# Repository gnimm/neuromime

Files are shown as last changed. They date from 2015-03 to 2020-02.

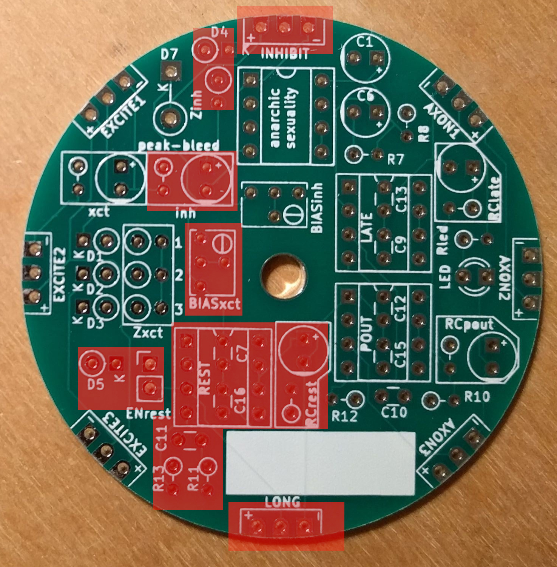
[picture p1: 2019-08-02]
1.0.1_minor_corrections_post_MUTEK/sketches_notes/dontsolder.jpg

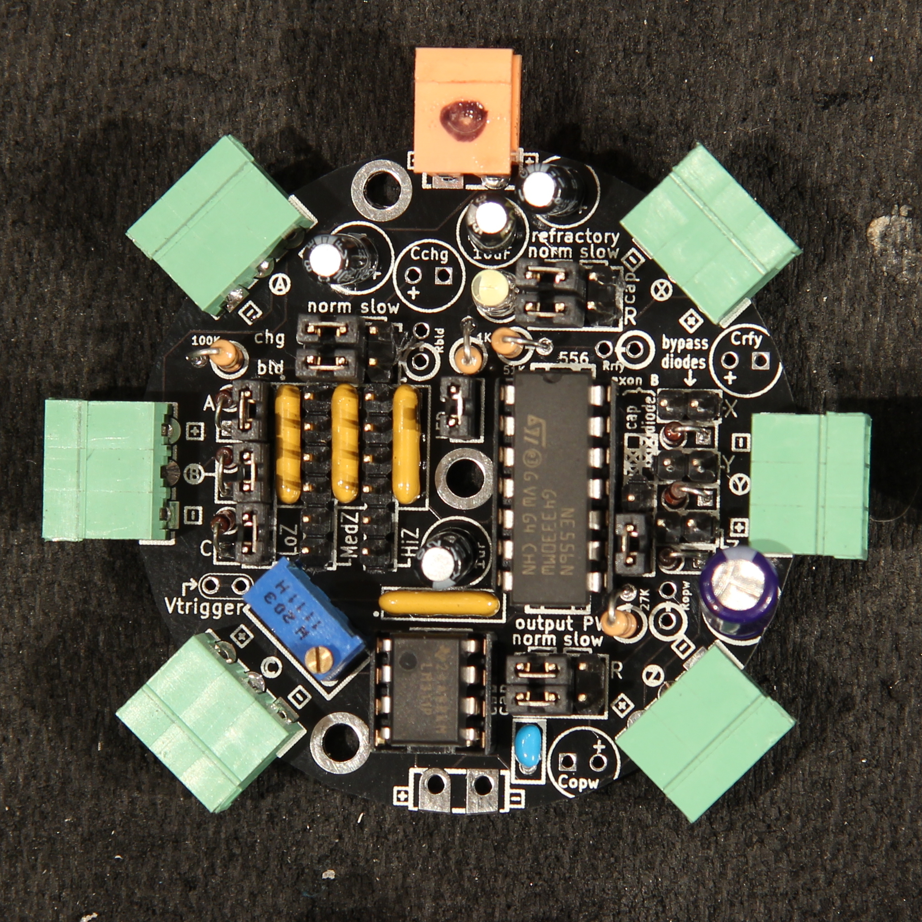
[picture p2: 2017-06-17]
ref/NEUROMIME_IO.jpg

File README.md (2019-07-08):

The “neuromime” is an electronic model of an organic nerve cell that can be interconnected in chains and loops. It is released here as an open-source hardware project in a collaborative effort by artists Norman White (original concept and design) and Peter Flemming (revision, expansion). Neuromimes are intended for (but not limited to) use in the creation of electro-physical artworks. Neuromimes can also function as the modular core of laboratory-style workshops where participants collectively generate an artwork for exhibition. Neuromimes are extensible building blocks, ideally suited to a collective making setting and/or generative, interactive artworks. Reminiscent of an exquisite corpse, they provide a framework that, while structured, is not scripted.

LINKS

Norman White speaking on the Neuromime at Interaccess (8'00"): https://www.youtube.com/watch?v=ue9ZF_hO-PE

Norman White on wikipedia: http://en.wikipedia.org/wiki/Norman_White

Norman White's website with other projects: http://normill.ca/

Peter Flemming's website with other projects: http://peterflemming.net

PROPERTIES OF AN ORGANIC NEURON

1. All-or-Nothing – It either fires completely or not at all (in this way it is "digital").

2. Temporal Summation – It can be made to fire by triggering one dendrite receptor repeatedly over time.

3. Spatial Summation – It can be made to fire by triggering several of its dendrite receptors simultaneously or virtually so.

4. Latency – It takes awhile for the impulse to travel from the dendrite receptor(s) along the axon to the output points (terminals).

5. Refractory Period – Once fired, it rests awhile before it can respond to stimuli again. 

TECHNICAL

-these folders contains files for a printed circuit board generated with KiCad, build: (2012-apr-16-27), http://www.kicad-pcb.org

-important technical annotation is contained in Norman's original schematic in the "ref" folder

-supplementary files (other schematics, visual information) are in the folder "ref"

-see the index below for detailed description of folder contents and files‎

INDEX (most folders have a detailed index as well)

1.0.0/

   ---this folder contains the Neuromime board files, schematics, fabrication outputs (Gerber etc.) done in KiCad

kicadlibs/

   ---folder contains footprint and schematic device libraries used in Neuromime not included in standard KiCad

ref/

   ---folder for supplementary files (Norman's original schematic, other visual information etc.)

LICENSE.txt

   ---Creative Commons license

README.md

   ---this file

TODO.txt

   ---errors, to do, future versions, suggestions, comments

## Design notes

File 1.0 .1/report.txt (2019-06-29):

Info: Backing up file "/home/gnimm/projects/schematics_pcb/neuromime/1.1.0/project_files/sym-lib-table" to file "/home/gnimm/projects/schematics_pcb/neuromime/1.1.0/project_files/rescue-backup/sym-lib-table-2018-11-04-21-16-39".
Info: Backing up file "/home/gnimm/projects/schematics_pcb/neuromime/1.1.0/project_files/neuromime_1.0.0.sch" to file "/home/gnimm/projects/schematics_pcb/neuromime/1.1.0/project_files/rescue-backup/neuromime_1.0.0-2018-11-04-21-16-39.sch".
Info: Backing up file "/home/gnimm/projects/schematics_pcb/neuromime/1.1.0/project_files/neuromime_1.0.0.pro" to file "/home/gnimm/projects/schematics_pcb/neuromime/1.1.0/project_files/rescue-backup/neuromime_1.0.0-2018-11-04-21-16-39.pro".
Info: Backing up file "/home/gnimm/projects/schematics_pcb/neuromime/1.1.0/project_files/neuromime_1.0.0-cache.lib" to file "/home/gnimm/projects/schematics_pcb/neuromime/1.1.0/project_files/rescue-backup/neuromime_1.0.0-cache-2018-11-04-21-16-39.lib".
Info: Backing up file "/home/gnimm/projects/schematics_pcb/neuromime/1.1.0/project_files/neuromime_1.0.0-rescue.lib" to file "/home/gnimm/projects/schematics_pcb/neuromime/1.1.0/project_files/rescue-backup/neuromime_1.0.0-rescue-2018-11-04-21-16-39.lib".
Info: Backing up file "/home/gnimm/projects/schematics_pcb/neuromime/1.1.0/project_files/neuromime_1.0.0-rescue.dcm" to file "/home/gnimm/projects/schematics_pcb/neuromime/1.1.0/project_files/rescue-backup/neuromime_1.0.0-rescue-2018-11-04-21-16-39.dcm".
Info: Adding library "neuromime_1.0.0-rescue", file "${KIPRJMOD}/neuromime_1.0.0-rescue.lib" to project symbol library table.
Symbol "3_RESISTOR_PACK_BUSSED" mapped to symbol library "neuromime_1.0.0-rescue".
Symbol "3_RESISTOR_PACK_BUSSED" mapped to symbol library "neuromime_1.0.0-rescue".
Symbol "3_RESISTOR_PACK_BUSSED" mapped to symbol library "neuromime_1.0.0-rescue".
Symbol "GND" mapped to symbol library "neuromime_1.0.0-rescue".
Symbol "CONN_1" mapped to symbol library "neuromime_1.0.0-rescue".
Symbol "CONN_1" mapped to symbol library "neuromime_1.0.0-rescue".
Symbol "GND" mapped to symbol library "neuromime_1.0.0-rescue".
Symbol "GND" mapped to symbol library "neuromime_1.0.0-rescue".
Symbol "CONN_1" mapped to symbol library "neuromime_1.0.0-rescue".
Symbol "TEST" mapped to symbol library "neuromime_1.0.0-rescue".
Symbol "CP" mapped to symbol library "neuromime_1.0.0-rescue".
Symbol "JUMPER3" mapped to symbol library "neuromime_1.0.0-rescue".
Symbol "VCC" mapped to symbol library "power".
Symbol "VCC" mapped to symbol library "power".
Symbol "VCC" mapped to symbol library "power".
Symbol "GND" mapped to symbol library "neuromime_1.0.0-rescue".
Symbol "CONN_3" mapped to symbol library "neuromime_1.0.0-rescue".
Symbol "CONN_3" mapped to symbol library "neuromime_1.0.0-rescue".
Symbol "CONN_3" mapped to symbol library "neuromime_1.0.0-rescue".
Symbol "3_RESISTOR_PACK_BUSSED" mapped to symbol library "neuromime_1.0.0-rescue".
Symbol "VCC" mapped to symbol library "power".
Symbol "GND" mapped to symbol library "neuromime_1.0.0-rescue".
Symbol "JUMPER" mapped to symbol library "neuromime_1.0.0-rescue".
Symbol "JUMPER" mapped to symbol library "neuromime_1.0.0-rescue".
Symbol "CONN_3" mapped to symbol library "neuromime_1.0.0-rescue".
Symbol "JUMPER" mapped to symbol library "neuromime_1.0.0-rescue".
Symbol "DIODE" mapped to symbol library "neuromime_1.0.0-rescue".
Symbol "DIODE" mapped to symbol library "neuromime_1.0.0-rescue".
Symbol "JUMPER" mapped to symbol library "neuromime_1.0.0-rescue".
Symbol "CONN_3" mapped to symbol library "neuromime_1.0.0-rescue".
Symbol "JUMPER" mapped to symbol library "neuromime_1.0.0-rescue".
Symbol "JUMPER" mapped to symbol library "neuromime_1.0.0-rescue".
Symbol "GND" mapped to symbol library "neuromime_1.0.0-rescue".
Symbol "VCC" mapped to symbol library "power".
Symbol "C" mapped to symbol library "neuromime_1.0.0-rescue".
Symbol "VCC" mapped to symbol library "power".
Symbol "GND" mapped to symbol library "neuromime_1.0.0-rescue".
Symbol "JUMPER" mapped to symbol library "neuromime_1.0.0-rescue".
Symbol "DIODE" mapped to symbol library "neuromime_1.0.0-rescue".
Symbol "DIODE" mapped to symbol library "neuromime_1.0.0-rescue".
Symbol "JUMPER" mapped to symbol library "neuromime_1.0.0-rescue".
Symbol "GND" mapped to symbol library "neuromime_1.0.0-rescue".
Symbol "JUMPER" mapped to symbol library "neuromime_1.0.0-rescue".
Symbol "DIODE" mapped to symbol library "neuromime_1.0.0-rescue".
Symbol "LED" mapped to symbol library "neuromime_1.0.0-rescue".
Symbol "JUMPER" mapped to symbol library "neuromime_1.0.0-rescue".
Symbol "R" mapped to symbol library "neuromime_1.0.0-rescue".
Symbol "GND" mapped to symbol library "neuromime_1.0.0-rescue".
Symbol "VCC" mapped to symbol library "power".
Symbol "C" mapped to symbol library "neuromime_1.0.0-rescue".
Symbol "GND" mapped to symbol library "neuromime_1.0.0-rescue".
Symbol "VCC" mapped to symbol library "power".
Symbol "GND" mapped to symbol library "neuromime_1.0.0-rescue".
Symbol "GND" mapped to symbol library "neuromime_1.0.0-rescue".
Symbol "C" mapped to symbol library "neuromime_1.0.0-rescue".
Symbol "GND" mapped to symbol library "neuromime_1.0.0-rescue".
Symbol "C" mapped to symbol library "neuromime_1.0.0-rescue".
Symbol "C" mapped to symbol library "neuromime_1.0.0-rescue".
Symbol "C" mapped to symbol library "neuromime_1.0.0-rescue".
Symbol "VCC" mapped to symbol library "power".
Symbol "CP" mapped to symbol library "neuromime_1.0.0-rescue".
Symbol "CP" mapped to symbol library "neuromime_1.0.0-rescue".
Symbol "CP" mapped to symbol library "neuromime_1.0.0-rescue".
Symbol "R" mapped to symbol library "neuromime_1.0.0-rescue".
Symbol "GND" mapped to symbol library "neuromime_1.0.0-rescue".
Symbol "JUMPER3" mapped to symbol library "neuromime_1.0.0-rescue".
Symbol "JUMPER3" mapped to symbol library "neuromime_1.0.0-rescue".
Symbol "R" mapped to symbol library "neuromime_1.0.0-rescue".
Symbol "VCC" mapped to symbol library "power".
Symbol "VCC" mapped to symbol library "power".
Symbol "GND" mapped to symbol library "neuromime_1.0.0-rescue".
Symbol "VCC" mapped to symbol library "power".
Symbol "GND" mapped to symbol library "neuromime_1.0.0-rescue".
Symbol "CP" mapped to symbol library "neuromime_1.0.0-rescue".
Symbol "CP" mapped to symbol library "neuromime_1.0.0-rescue".
Symbol "JUMPER3" mapped to symbol library "neuromime_1.0.0-rescue".
Symbol "VCC" mapped to symbol library "power".
Symbol "R" mapped to symbol library "neuromime_1.0.0-rescue".
Symbol "JUMPER3" mapped to symbol library "neuromime_1.0.0-rescue".
Symbol "GND" mapped to symbol library "neuromime_1.0.0-rescue".
Symbol "R" mapped to symbol library "neuromime_1.0.0-rescue".
Symbol "R" mapped to symbol library "neuromime_1.0.0-rescue".
Symbol "JUMPER3" mapped to symbol library "neuromime_1.0.0-rescue".
Symbol "JUMPER3" mapped to symbol library "neuromime_1.0.0-rescue".
Symbol "GND" mapped to symbol library "neuromime_1.0.0-rescue".
Symbol "R" mapped to symbol library "neuromime_1.0.0-rescue".
Symbol "CP" mapped to symbol library "neuromime_1.0.0-rescue".
Symbol "VCC" mapped to symbol library "power".
Symbol "GND" mapped to symbol library "neuromime_1.0.0-rescue".
Symbol "JUMPER" mapped to symbol library "neuromime_1.0.0-rescue".
Symbol "JUMPER" mapped to symbol library "neuromime_1.0.0-rescue".
Symbol "GND" mapped to symbol library "neuromime_1.0.0-rescue".
Symbol "CONN_2" mapped to symbol library "neuromime_1.0.0-rescue".
Symbol "CP" mapped to symbol library "neuromime_1.0.0-rescue".
Symbol "PWR_FLAG" mapped to symbol library "power".
Symbol "CONN_2" mapped to symbol library "neuromime_1.0.0-rescue".
Symbol "PWR_FLAG" mapped to symbol library "power".
Symbol "VCC" mapped to symbol library "power".
Symbol "CONN_3" mapped to symbol library "neuromime_1.0.0-rescue".
Symbol "POT" mapped to symbol library "neuromime_1.0.0-rescue".
Symbol "JUMPER" mapped to symbol library "neuromime_1.0.0-rescue".
Symbol "DIODE" mapped to symbol library "neuromime_1.0.0-rescue".
Symbol "556" mapped to symbol library "neuromime_1.0.0-rescue".
Symbol "LM311N" mapped to symbol library "neuromime_1.0.0-rescue".
Info: Symbol library table mapping complete!

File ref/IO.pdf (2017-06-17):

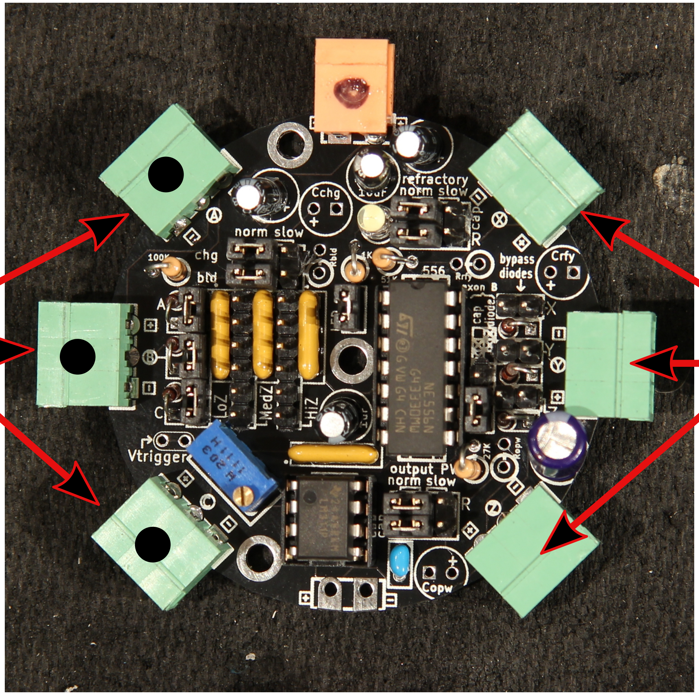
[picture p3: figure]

AXONS
(INPUTS)

DENDRITES
(OUTPUTS)

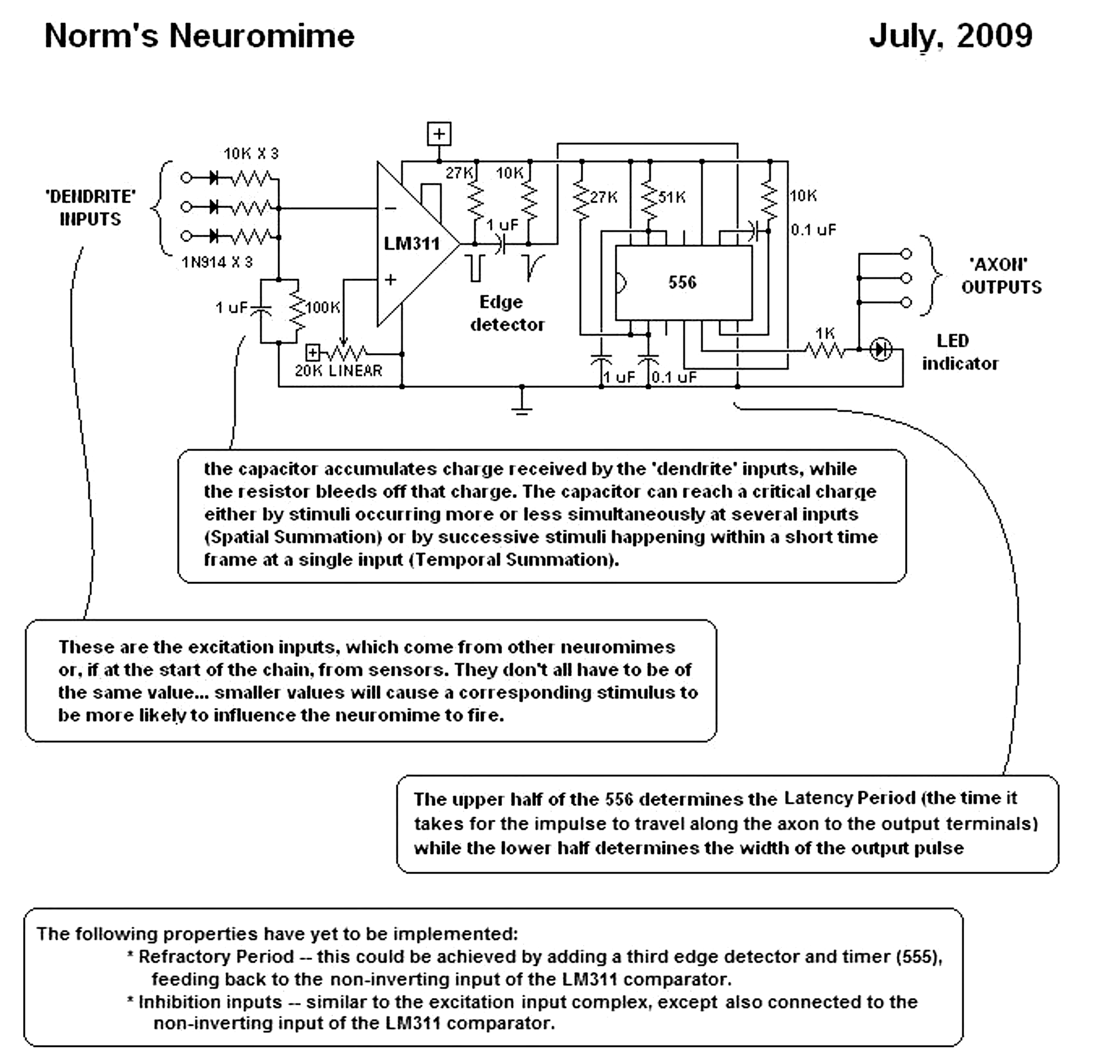
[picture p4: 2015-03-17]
ref/Neuromime_original_schematic_03.png

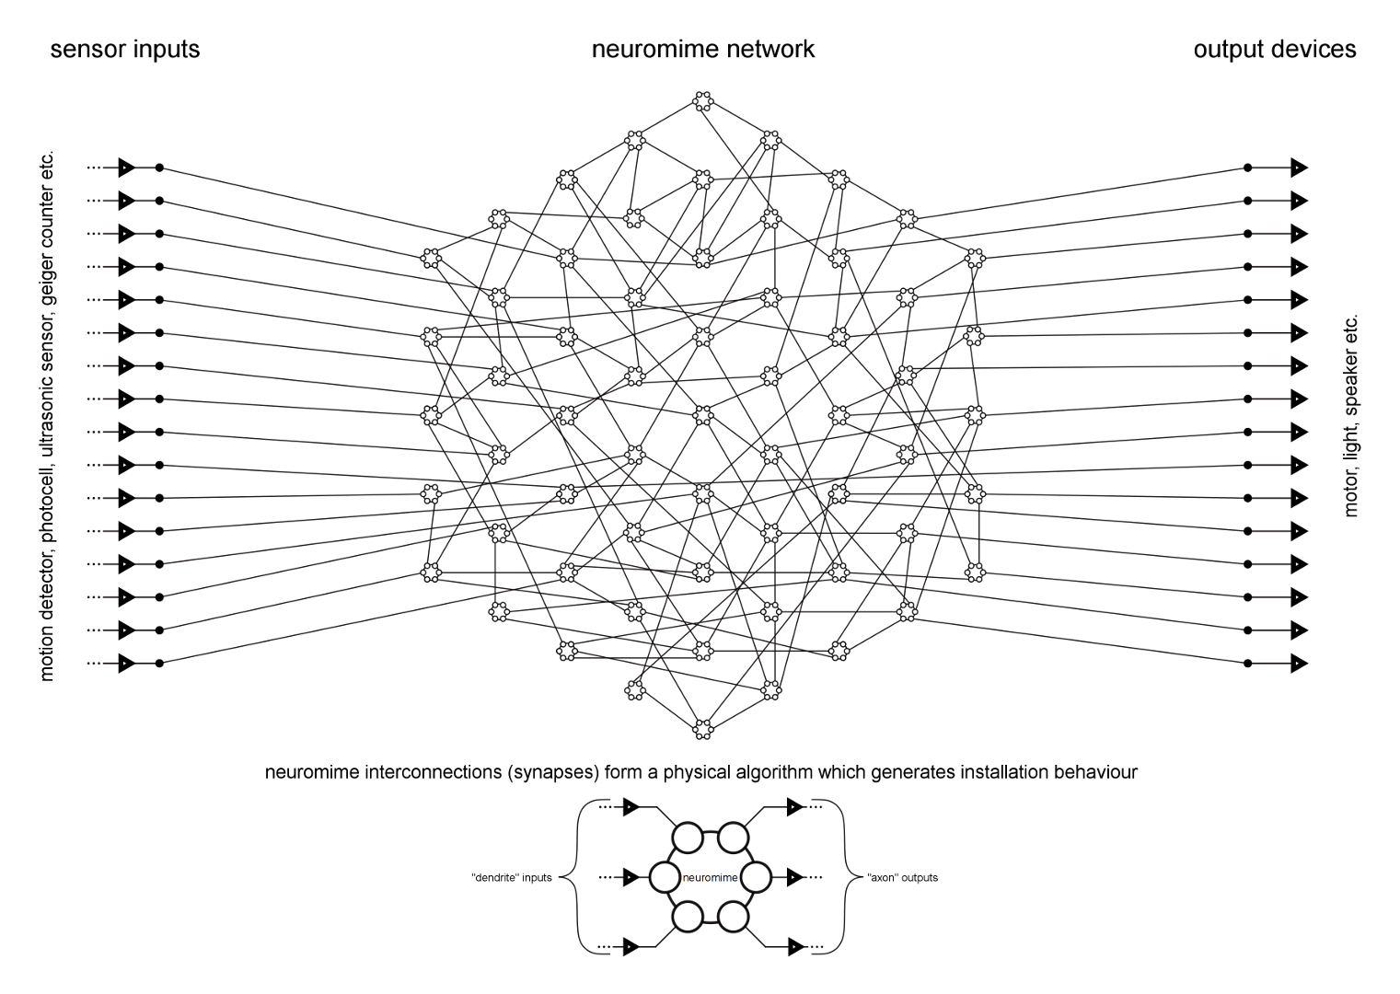
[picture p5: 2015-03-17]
ref/Neuromime_network_schematic.png

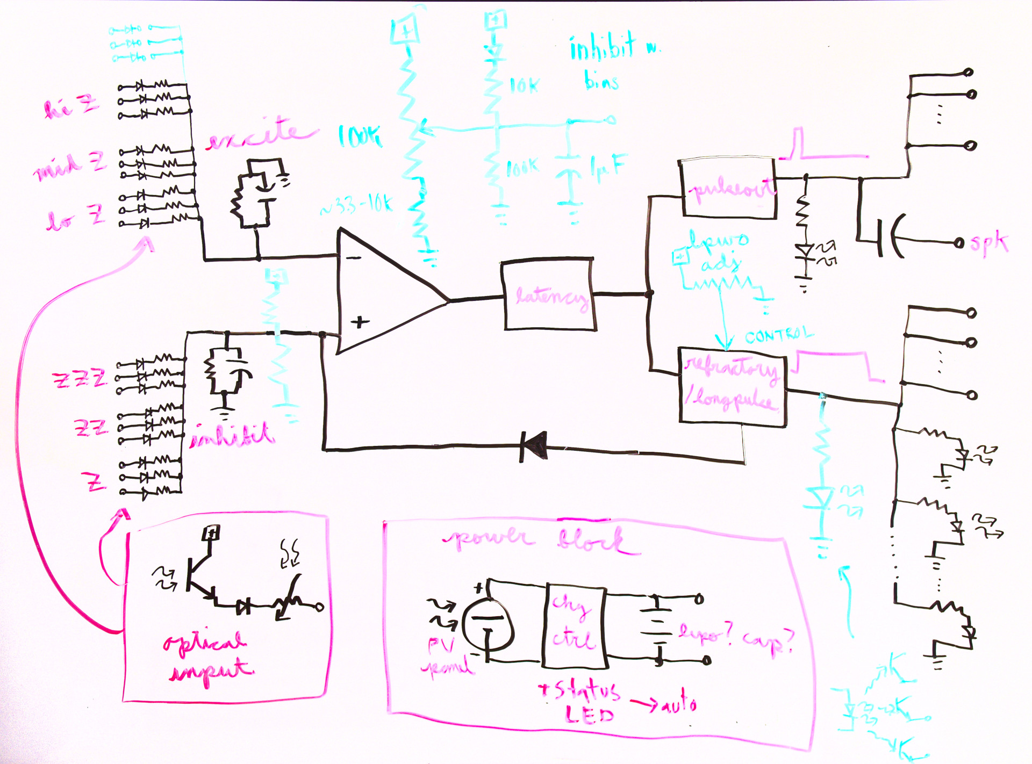
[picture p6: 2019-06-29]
1.0.1_minor_corrections_post_MUTEK/sketches_notes/2019-01_whiteboard_sketch_schematic_LORES.jpg

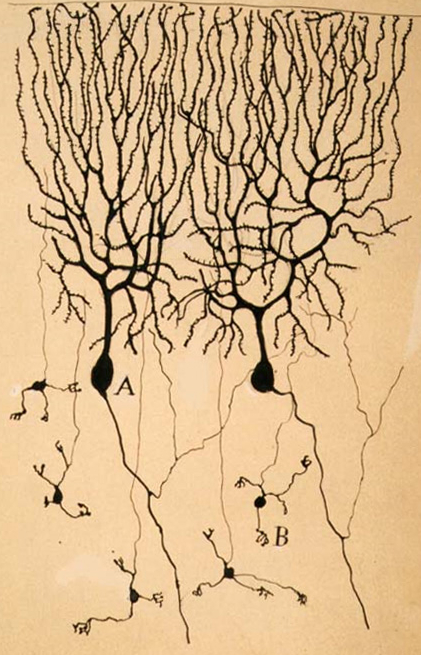
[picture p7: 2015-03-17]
ref/PurkinjeCell.jpg

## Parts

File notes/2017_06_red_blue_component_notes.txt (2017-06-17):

"red" neuromimes:
-quantity: 12
-implemented by Peter during EB residency, winter 2017 
-fiber optic output on axon B when 'cap' is selected w. axon B output jumper
-above jumper selects a 47 ohm resistor (soldered in place of 100uF cap)
-output PW cap, slow (red): 10uF
-output PW R, slow: 51K
timings:
		0.1uF	10uF
27K	2.97 mS	297 mS
51K	5.61 mS	561 mS

"blue" neuromimes:
-quantity: 9
-implemented by Peter for Stephen's 'Art and Artificial Life' class at NSCAD, summer 2017
-long output pulse
-output PW cap, slow: xxuF
-output PW R, slow: 47M
timings:
		0.1uF	100uF
27K	2.97 mS	xx S
47M	5.17 S	xx S

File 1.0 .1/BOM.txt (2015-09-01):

DIGIKEY PARTS LIST (shopping cart):
http://www.digikey.ca/short/tzpq7t

NB:
-this list is incomplete and in progress; missing at least the output LED (we used a 3mm super birght white LED), mating connector for the power pins and 8 pin DIP socket
-the power connectors used in orginal neuromime boards were purchased in Taiwan and identical ones do not seem to be available on Digikey (see alternate connectors below)
-possible cheaper alternates for connectors listed below; it should be possible to source nearly everything in bulk for cheap on sites like Ebay and/or Alibaba

ALTERNATE CONNECTORS:
3.96mm orange ones (for power):
   http://www.aliexpress.com/item/200PCS-HT396-HT396K-HT396R-2Pin-3-96mm-Right-Angle-Plug-in-Screw-Terminal-Block-ROHS/1079793360.html

3.5 mm green ones (for axon and dendrite connections):
   http://www.aliexpress.com/item/100PCS-2EDGK-3-81-3P-2EDGR-3-81-3P-2EDGK-2EDGR-3Pin-3-81mm-Right-Angle/1083116785.html

3.5mm combicon connectors from Digikey (would work for axon and dendrite connectors):
   277-1707-ND - terminal block - http://www.digikey.ca/product-detail/en/1984028/277-1707-ND/950835
   277-1750-ND - pin header - http://www.digikey.ca/product-detail/en/1945106/277-1750-ND/950878

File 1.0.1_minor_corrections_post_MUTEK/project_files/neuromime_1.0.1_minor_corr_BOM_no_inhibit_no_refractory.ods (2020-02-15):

Reference | Value | per, green boards A | per, green boards B | per yellow / white boards | extended | in inventory | need to order | preferred supplier | board label (if different from reference) | notes | MFPN | part link
C1 C17 | 10uF | 1 | 2 | 2 | 200 |  | 200 | dk | C17, green boards: RCrest (capacitor) C17, yellow/white boards: C_rest |  | 860010472002 | https://www.digikey.ca/product-detail/en/wurth-electronics-inc/860010472002/732-8625-1-ND/5728581
C4 C5 C6 C8 | 1uF | 1 | 4 | 4 | 400 |  | 400 | dk | C4: peak-bleed INH (capacitor) C5: peak-bleed XCT (capacitor) C8: Rclate (capacitor) |  | 860020672005 | https://www.digikey.ca/product-detail/en/wurth-electronics-inc/860020672005/732-8851-1-ND/5728796
C7 C9 C10 C11 C12 C13 C14 C15 C16 | 0.1uF | 3 | 8 | 8 | 800 |  | 800 | dk | C14: Rcpout (capacitor) | C7, C9, C12, C13, C15, C16 go on underside of board | C315C104M5U5TA | https://www.digikey.ca/product-detail/en/kemet/C315C104M5U5TA/399-4151-ND/817927
D1 D2 D3 D4 D5 | 1N4148 | 2 | 5 | 5 | 500 |  | 500 | dk |  | on green boards only: silkscreen is backwards, K indicates anode | 1N4148 | https://www.digikey.ca/product-detail/en/1N4148/1N4148FS-ND/458603/?itemSeq=298038621
D6 | LED 3mm | 0 | 1 | 1 | 100 |  | 100 | ali | LED |  | INL-3AB30 | https://www.digikey.ca/product-detail/en/inolux/INL-3AB30/1830-1005-ND/7604618
D7 | 1N4001 | 0 | 1 | 1 | 100 |  | 100 | dk |  |  | 1N4001-G | https://www.digikey.ca/product-detail/en/comchip-technology/1N4001-G/641-1310-1-ND/1979675
K1 K2 K3 K4 | 3p SIP socket | 1 | 4 | 4 | 400 |  | 400 | ali | K1: INHIBIT K2-4: EXCITE 1-3 |  | SSQ-103-02-T-S-RA | https://www.digikey.ca/product-detail/en/SSQ-103-02-T-S-RA/SAM1195-03-ND/1111409/?itemSeq=297654833
P2 P3 P4 P5 | 3p pin header | 1 | 4 | 4 | 400 |  | 400 | ali | P2-4: AXON 1-3 P5: LONG |  | PRPC003SGAN-M71RC | https://www.digikey.ca/product-detail/en/sullins-connector-solutions/PRPC003SGAN-M71RC/S1311EC-03-ND/2775451
R1 R2 R3 R4 R8 R10 R11 R12 R13 | 10K | 3 | 9 | 9 | 900 |  | 900 | dk | R1-3: Zxct R4: Zinh | R1-3 (Zxct) vertically mounted resistors, wire loop towards inside of board | CF14JT10K0 | https://www.digikey.ca/product-detail/en/CF14JT10K0/CF14JT10K0CT-ND/1830374/?itemSeq=297515842
R15 | 680R | 0 | 1 | 1 | 100 |  | 100 | dk | Rled |  | CF14JT680R | https://www.digikey.ca/product-detail/en/stackpole-electronics-inc/CF14JT680R/CF14JT680RCT-ND/1830346
R5 R6 | 100K | 1 | 2 | 2 | 200 |  | 200 | dk | R5: peak-bleed INH (resistor) R6: peak-bleed XCT (resistor) |  | CF14JT100K | https://www.digikey.ca/product-detail/en/stackpole-electronics-inc/CF14JT100K/CF14JT100KCT-ND/1830399
R7 R14 | 27K | 0 | 2 | 2 | 200 |  | 200 | dk | R14: Rcpout (resistor) |  | CF14JT27K0 | https://www.digikey.ca/product-detail/en/stackpole-electronics-inc/CF14JT27K0/CF14JT27K0CT-ND/1830385
R9 | 51K | 0 | 1 | 1 | 100 |  | 100 | dk | Rclate (resistor) |  | CF14JT51K0 | https://www.digikey.ca/product-detail/en/stackpole-electronics-inc/CF14JT51K0/CF14JT51K0CT-ND/1830392
R16 | 100K | 1 | 1 | 0 | 0 |  | 0 | dk | Rcrest (resistor)
RV1 RV2 | 10K trimmer | 1 | 2 | 3 | 300 |  | 300 | ali | RV1: BIASinh RV2: BIASxct |  | 1-1623849-0 | https://www.digikey.ca/product-detail/en/te-connectivity-passive-product/1-1623849-0/A105870-ND/2363126
RV3 | 1M trimmer | 0 | 0 | 1 | 100 |  | 100 | ali | RV3: VARrest
U1 | LM311 | 0 | 1 | 1 | 100 |  | 100 | ?? | anarchic sexuality |  | LM311P | https://www.digikey.ca/product-detail/en/texas-instruments/LM311P/296-1389-5-ND/277038
U2 U3 | 555 | 1 | 3 | 3 | 300 |  | 300 | ?? | U2: LATE U3: POUT U4: REST |  | SE555P | https://www.digikey.ca/product-detail/en/SE555P/296-9684-5-ND/380221/?itemSeq=297424092
SW1 | SW_push_dual | 0 | 0 | 1 | 100 | 0 | 100 | ali | sTaRt | optional start switch, white / yellow boards only, not required for all boards
IC sockets | 8 pin DIP | 1 | 4 | 4 | 400 |  | 400 | ali |  |  | ICS-308-T | https://www.digikey.ca/product-detail/en/adam-tech/ICS-308-T/2057-ICS-308-T-ND/9829299
spacer | 5/16” | 1 | 1 | 1 | 100 |  | 100 | ?? |  |  | 9912-312 | https://www.digikey.ca/product-detail/en/9912-312/492-1120-ND/586440/?itemSeq=297947991
# green boards A (no inhibit/refractory) |  |  | these are the boards used in August 2019 for MUTEK, with certain parts left unsoldered
# green boards B (blank) |  |  | these are the blank unused boards leftover from August 2019
# yellow / white boards (blank) | 100 |  | these are blank boards, printed after MUTEK in August 2019, with minor corrections arising

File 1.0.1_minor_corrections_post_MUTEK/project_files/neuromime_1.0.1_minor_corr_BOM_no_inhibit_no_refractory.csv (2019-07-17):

Reference | qty | Value | supplier/note | ext | MFPN | part link | qty. booards: | 100
C1 | 1 | 10uF |  | 100 | 860010472002 | https://www.digikey.ca/product-detail/en/wurth-electronics-inc/860010472002/732-8625-1-ND/5728581
C5 C6 C8 | 3 | 1uF |  | 300 | 860020672005 | https://www.digikey.ca/product-detail/en/wurth-electronics-inc/860020672005/732-8851-1-ND/5728796
C10 C11 C12 C13 C15 C16 C7 C9 C14 | 8 | 0.1uF |  | 800 | C315C104M5U5TA | https://www.digikey.ca/product-detail/en/kemet/C315C104M5U5TA/399-4151-ND/817927
D1 D2 D3 D4 D5 | 5 | 1N4148 |  | 500 | 1N4148 | https://www.digikey.ca/product-detail/en/1N4148/1N4148FS-ND/458603/?itemSeq=298038621
D6 | 1 | LED 3mm |  | 100 | INL-3AB30 | https://www.digikey.ca/product-detail/en/inolux/INL-3AB30/1830-1005-ND/7604618
D7 | 1 | 1N4001 |  | 100 | 1N4001-G | https://www.digikey.ca/product-detail/en/comchip-technology/1N4001-G/641-1310-1-ND/1979675
K1 K2 K3 K4 | 3 | 3p SIP socket |  | 400 | SSQ-103-02-T-S-RA | https://www.digikey.ca/product-detail/en/SSQ-103-02-T-S-RA/SAM1195-03-ND/1111409/?itemSeq=297654833K1 K2 K3 K4
P2 P3 P4 P5 | 3 | 3p pin header | Addison | 400
R1 R2 R3 R10 R11 R12 R13 R8 | 8 | 10K |  | 800 | CF14JT10K0 | https://www.digikey.ca/product-detail/en/CF14JT10K0/CF14JT10K0CT-ND/1830374/?itemSeq=297515842
R15 | 1 | 680R |  | 100 | CF14JT680R | https://www.digikey.ca/product-detail/en/stackpole-electronics-inc/CF14JT680R/CF14JT680RCT-ND/1830346
R6 | 1 | 100K |  | 100 | CF14JT100K | https://www.digikey.ca/product-detail/en/stackpole-electronics-inc/CF14JT100K/CF14JT100KCT-ND/1830399
R7 R14 | 2 | 27K |  | 200 | CF14JT27K0 | https://www.digikey.ca/product-detail/en/stackpole-electronics-inc/CF14JT27K0/CF14JT27K0CT-ND/1830385
R9 | 1 | 51K |  | 100 | CF14JT51K0 | https://www.digikey.ca/product-detail/en/stackpole-electronics-inc/CF14JT51K0/CF14JT51K0CT-ND/1830392
RV2 | 1 | 10K trimmer | Addison | 100 | 1-1623849-0 | https://www.digikey.ca/product-detail/en/te-connectivity-passive-product/1-1623849-0/A105870-ND/2363126
U1 | 1 | LM311 |  | 100 | LM311P | https://www.digikey.ca/product-detail/en/texas-instruments/LM311P/296-1389-5-ND/277038
U2 U3 | 2 | 555 |  | 200 | SE555P | https://www.digikey.ca/product-detail/en/SE555P/296-9684-5-ND/380221/?itemSeq=297424092
IC sockets | 3 | 8 pin DIP | Addison | 300 | ICS-308-T | https://www.digikey.ca/product-detail/en/adam-tech/ICS-308-T/2057-ICS-308-T-ND/9829299
spacer | 1 | 5/16” |  | 100 | 9912-312 | https://www.digikey.ca/product-detail/en/9912-312/492-1120-ND/586440/?itemSeq=297947991
pinheaders

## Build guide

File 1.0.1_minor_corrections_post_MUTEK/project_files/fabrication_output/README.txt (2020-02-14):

PCB NAME: neuromime_1.0.1_minor_corr
DATE: 2019-08-26
AUTHOR: Peter Flemming
CONTACT: info@peterflemming.net
PCB SOFTWARE USED: KiCad5/PcbNew

files in folder DRILL_DATA:
neuromime_1.0.1_minor_corr-NPTH_DRILLFILE.drl: Excellon drill file
neuromime_1.0.1_minor_corr-NPTH_DRILLMAP.pdf: drill map
neuromime_1.0.1_minor_corr_DRILL_REPORT.rpt: drill report
neuromime_1.0.1_minor_corr-NPTH_DRILLFILE.drl: Excellon drill file, non-plated through-holes
neuromime_1.0.1_minor_corr-NPTH_DRILLMAP.pdf: drill map, non-plated through-holes

files in folder GERBER_DATA:
neuromime_1.0.1_minor_corr_COPPER_BOTTOM_LAYER.gbr: copper layer, BOTTOM of board
neuromime_1.0.1_minor_corr_COPPER_TOP_LAYER.gbr: copper layer, TOP of board
neuromime_1.0.1_minor_corr_SOLDERMASK_BOTTOM.gbr: solder mask, BOTTOM of board
neuromime_1.0.1_minor_corr_SOLDERMASK_TOP.gbr: solder mask, TOP of board
neuromime_1.0.1_minor_corr_PCB_EDGES.gbr: PCB edges cut out
neuromime_1.0.1_minor_corr_SILKSCREEN_TOP.gbr: silkscreen/legend top of board
neuromime_1.0.1_minor_corr_SILKSCREEN_BOTTOM.gbr: silkscreen/legend bottom of board
neuromime_1.0.1_minor_corr_USER_REFERENCE.gbr: reference layer, contains dimensions, user notes, diagrams etc.

PRODUCTION NOTES:
-the GERBER format used by Pcbnew is RS274X format 4.6, mm, Leading zero omitted, Abs format

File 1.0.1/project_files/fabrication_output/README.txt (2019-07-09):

PCB NAME: neuromime_1.0.1
DATE: 2019-07-09
AUTHOR: Peter Flemming
CONTACT: info@peterflemming.net
PCB SOFTWARE USED: KiCad5/PcbNew

files in folder DRILL_DATA:
neuromime_1.0.1-NPTH_DRILLFILE.drl: Excellon drill file
neuromime_1.0.1-NPTH_DRILLMAP.pdf: drill map
*_DRILL_REPORT.rpt: drill report
neuromime_1.0.1-NPTH_DRILLFILE.drl: Excellon drill file, non-plated through-holes
neuromime_1.0.1-NPTH_DRILLMAP.pdf: drill map, non-plated through-holes

files in folder GERBER_DATA:
neuromime_1.0.1_COPPER_BOTTOM_LAYER.gbr: copper layer, BOTTOM of board
neuromime_1.0.1_COPPER_TOP_LAYER.gbr: copper layer, TOP of board
neuromime_1.0.1_SOLDERMASK_BOTTOM.gbr: solder mask, BOTTOM of board
neuromime_1.0.1_SOLDERMASK_TOP.gbr: solder mask, TOP of board
neuromime_1.0.1_PCB_EDGES.gbr: PCB edges cut out
neuromime_1.0.1_SILKSCREEN_TOP.gbr: silkscreen/legend top of board
neuromime_1.0.1_SILKSCREEN_BOTTOM.gbr: silkscreen/legend bottom of board
neuromime_1.0.1_USER_REFERENCE.gbr: reference layer, contains dimensions, user notes, diagrams etc.

PRODUCTION NOTES:
-the GERBER format used by Pcbnew is RS274X format 4.6, mm, Leading zero omitted, Abs format

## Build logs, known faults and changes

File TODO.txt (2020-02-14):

corrections/errors (Neuromime ver 1.0.0):
-correct refractory capacitor/resistor labelling to latency capacitor/resistor on top silkscreen layer
-correct axon labelling, top silkscreen layer

to do:
-implement inhibition input complex (on non-inverting input of LM311)
-implement refractory period (with another 555 timer)
-add bill-of-materials, in the meantime contact the maintainer (Peter)

suggestions/ideas:
-use individual 555 timers instead of 556 dual timer, this way could use low power version of 555, low power 556 not available
-surface mount version
-inhibition complex as out-board module for version 1.0.0
-make an output module (eg. SSR) in same form factor
-make a multiple cell board (eg. square or axonometric grid), with fixed number of external inputs and outputs, internal connections routable with jumpers, wirewrap connectors etc.

-high speed neuromimes, operating at, say, audio frequency (20hz-20khz)
-inspired by the "rate model", spiking neurons
-blinking lights become fading lights
-fiber optic connections then have variable strength (weights?) based on pulse frequency (LED brightness)
-could smooth high frequency (HF) neuromime outputs, connect directly to amp/speaker for wavering dissonant tones 
-HF outputs to dc motor speed (braitenberg?)

-add self-activation button on each neuron
-how to accomodate more than 3 I/O points?
-3D networks using bendable/rigid cabling or right-angle male-male headers, etc.
-neuromimes make Spiking Neural Networks (SNNs), which are more biologically plausible than continuous ANNs
-SNNs are used primarily in neuroscience reseach, while continuous ANNs are currently more "practical" problem solvers, i.e. they are easier to train for certain prediction problems and entirely the basis for the AI "revolution" circa 2016

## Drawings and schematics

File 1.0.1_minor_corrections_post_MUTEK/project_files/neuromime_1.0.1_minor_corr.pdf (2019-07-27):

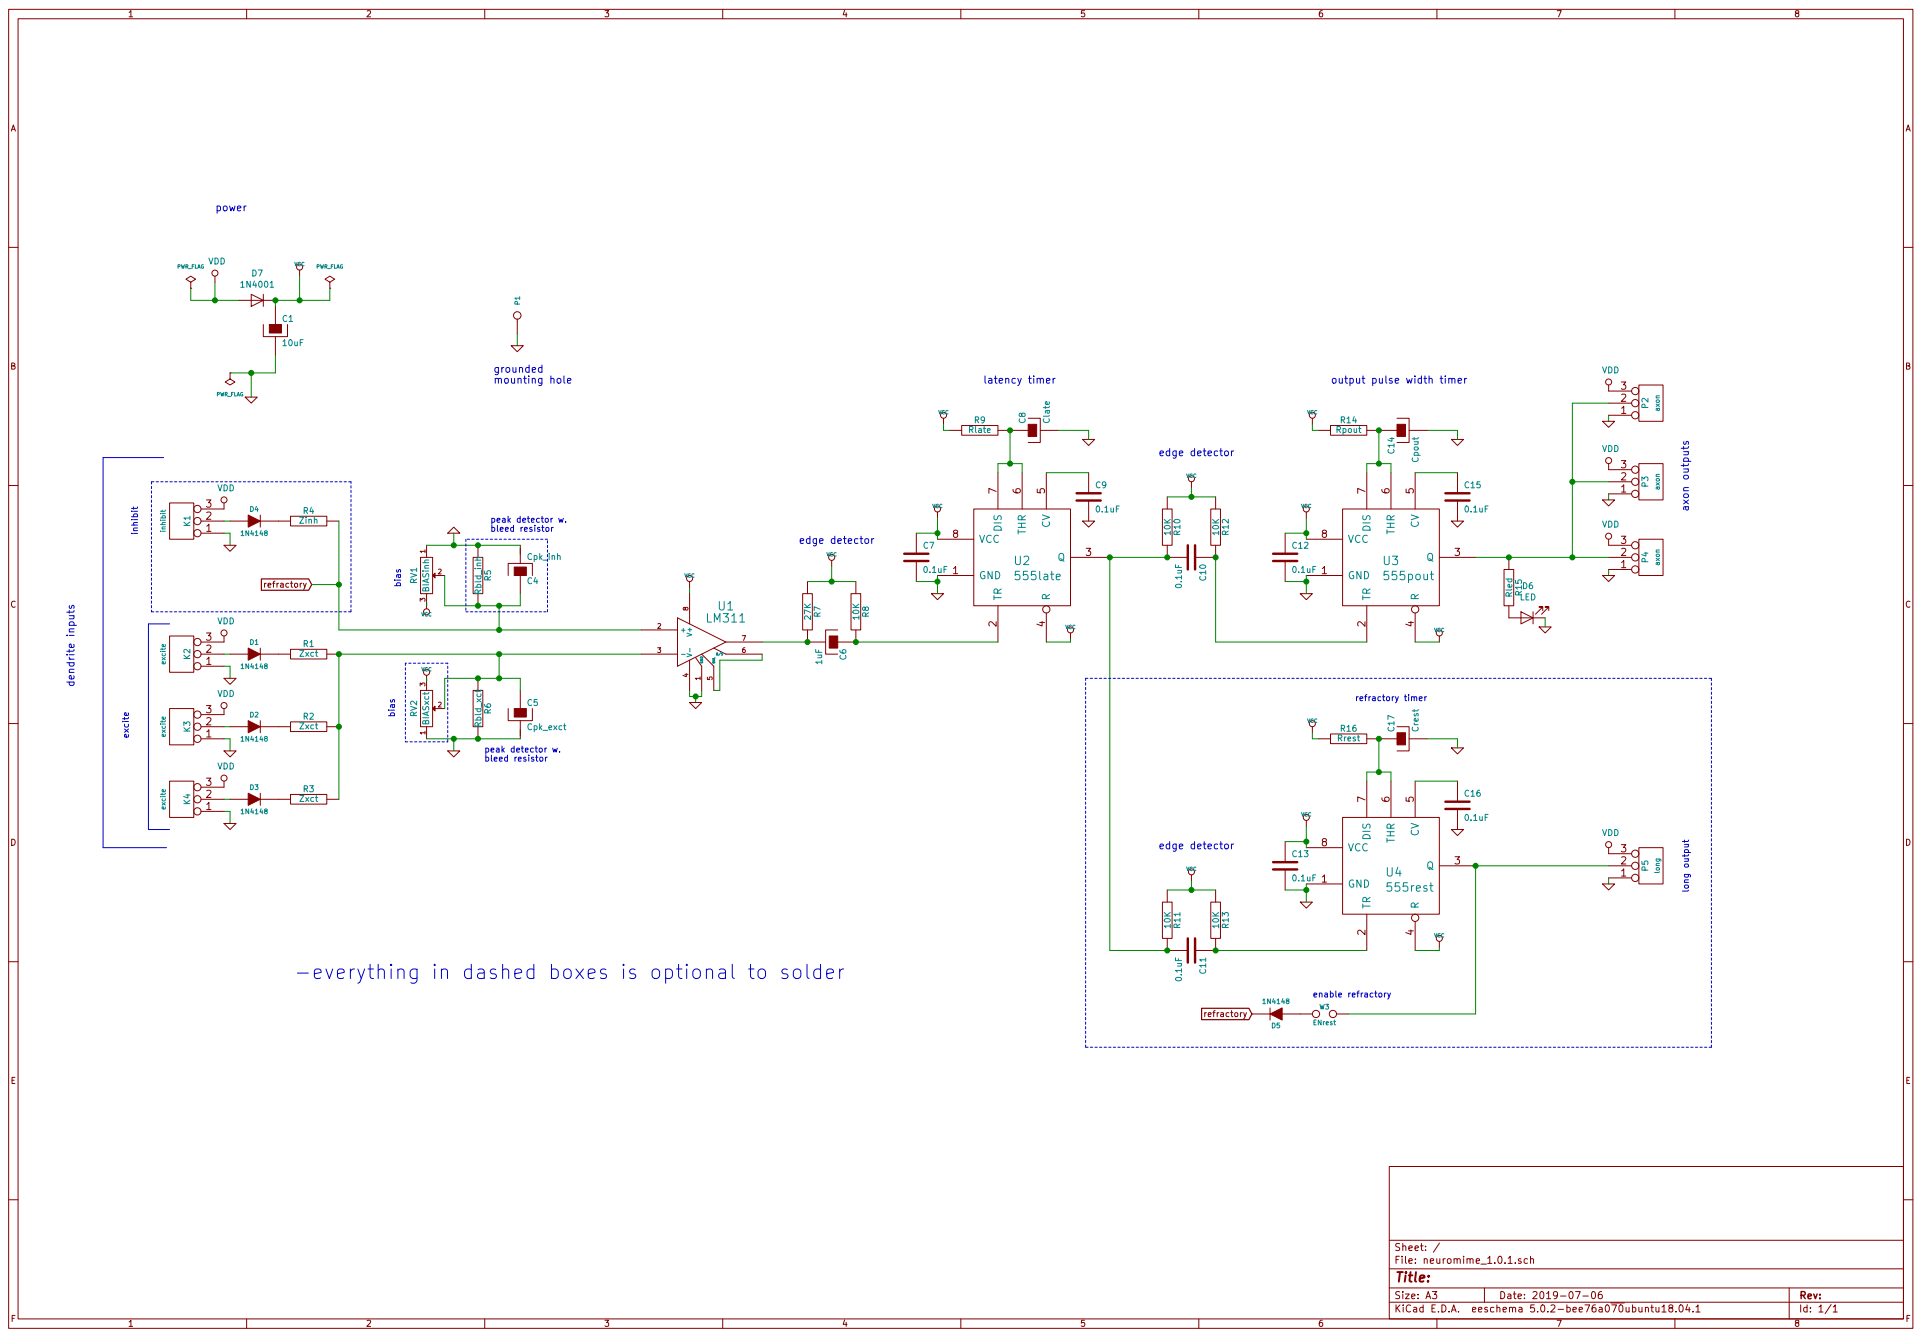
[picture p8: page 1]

Id: 1/1 Title: File: neuromime_1.0.1.sch Sheet: / P1 grounded mounting hole

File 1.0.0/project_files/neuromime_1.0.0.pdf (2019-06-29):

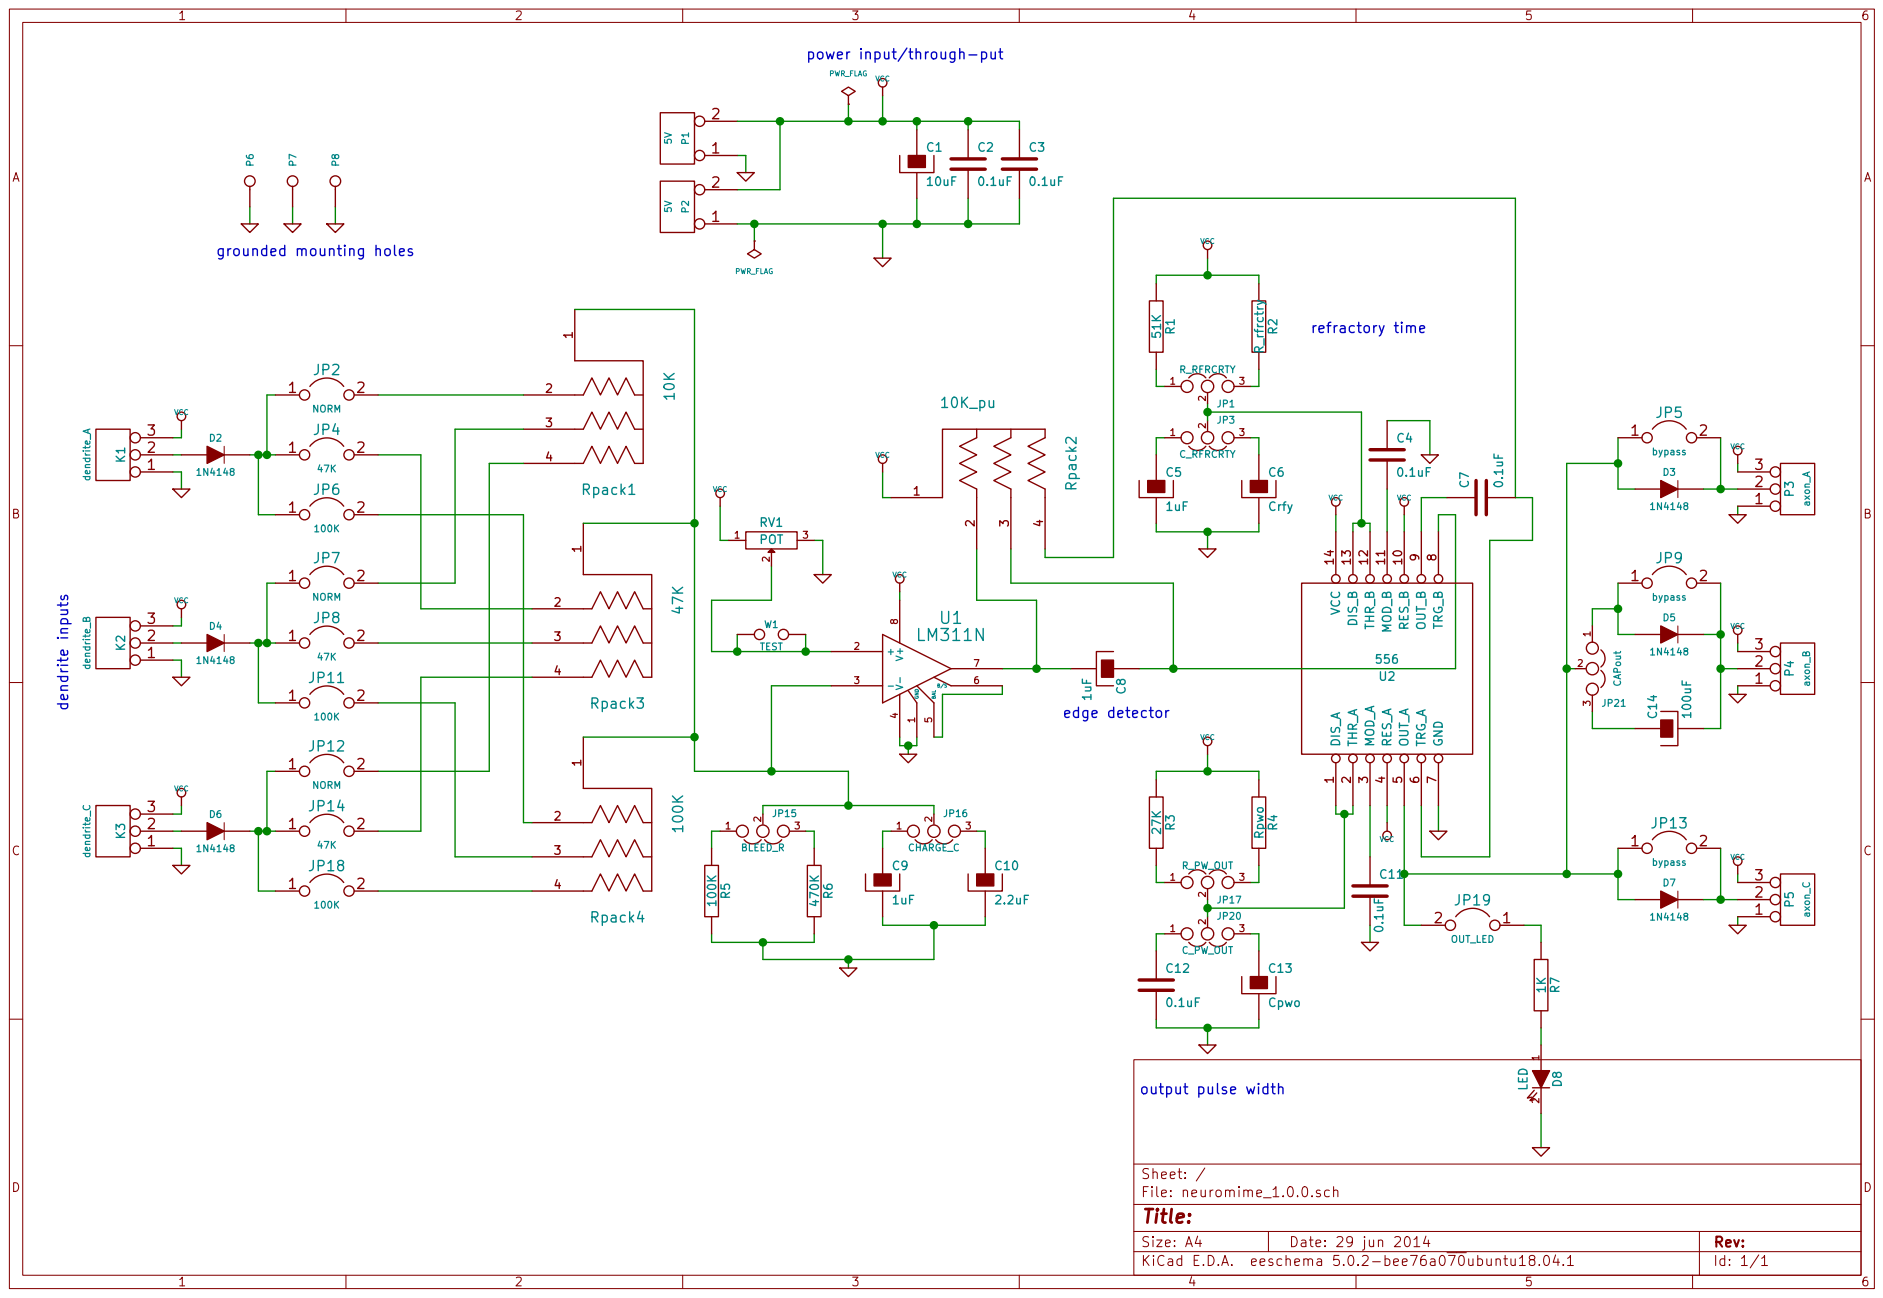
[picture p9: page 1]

0.1uF power input/through-put

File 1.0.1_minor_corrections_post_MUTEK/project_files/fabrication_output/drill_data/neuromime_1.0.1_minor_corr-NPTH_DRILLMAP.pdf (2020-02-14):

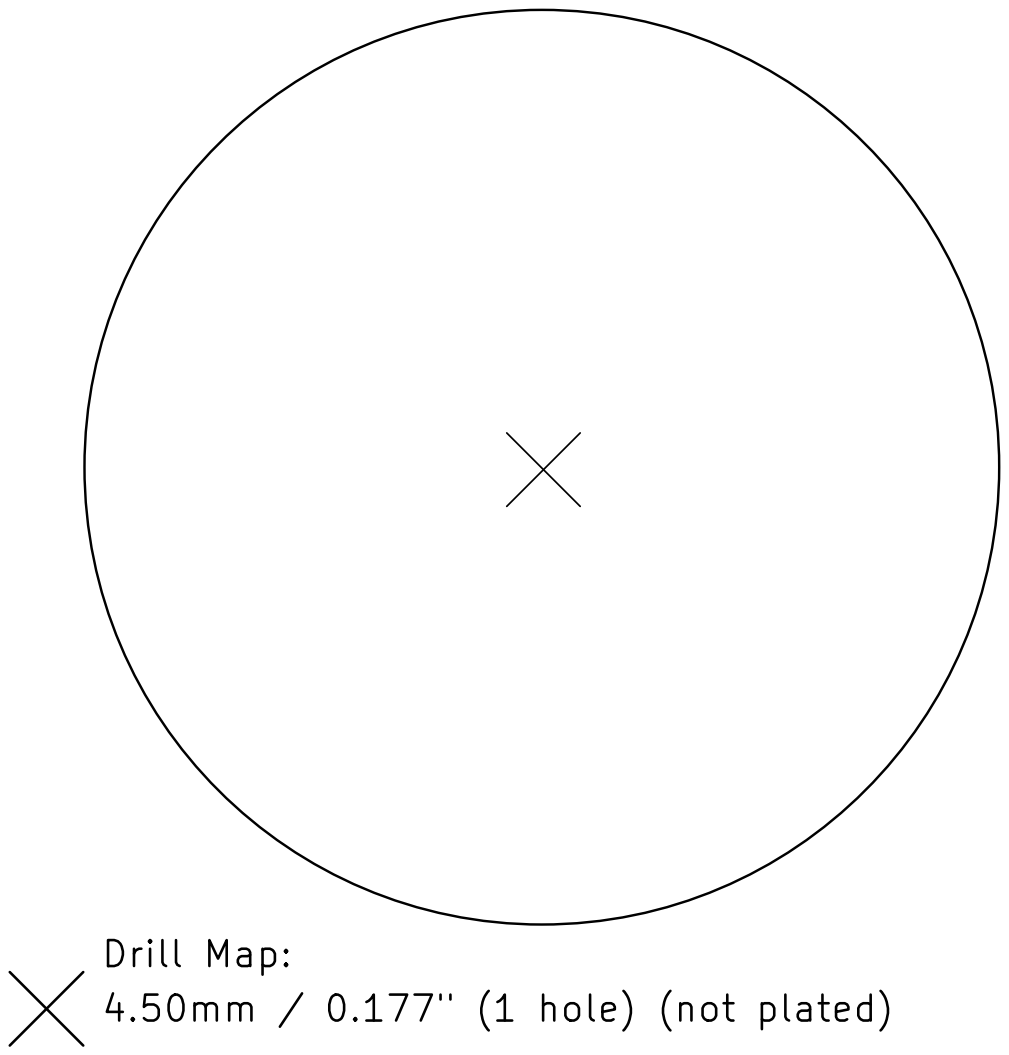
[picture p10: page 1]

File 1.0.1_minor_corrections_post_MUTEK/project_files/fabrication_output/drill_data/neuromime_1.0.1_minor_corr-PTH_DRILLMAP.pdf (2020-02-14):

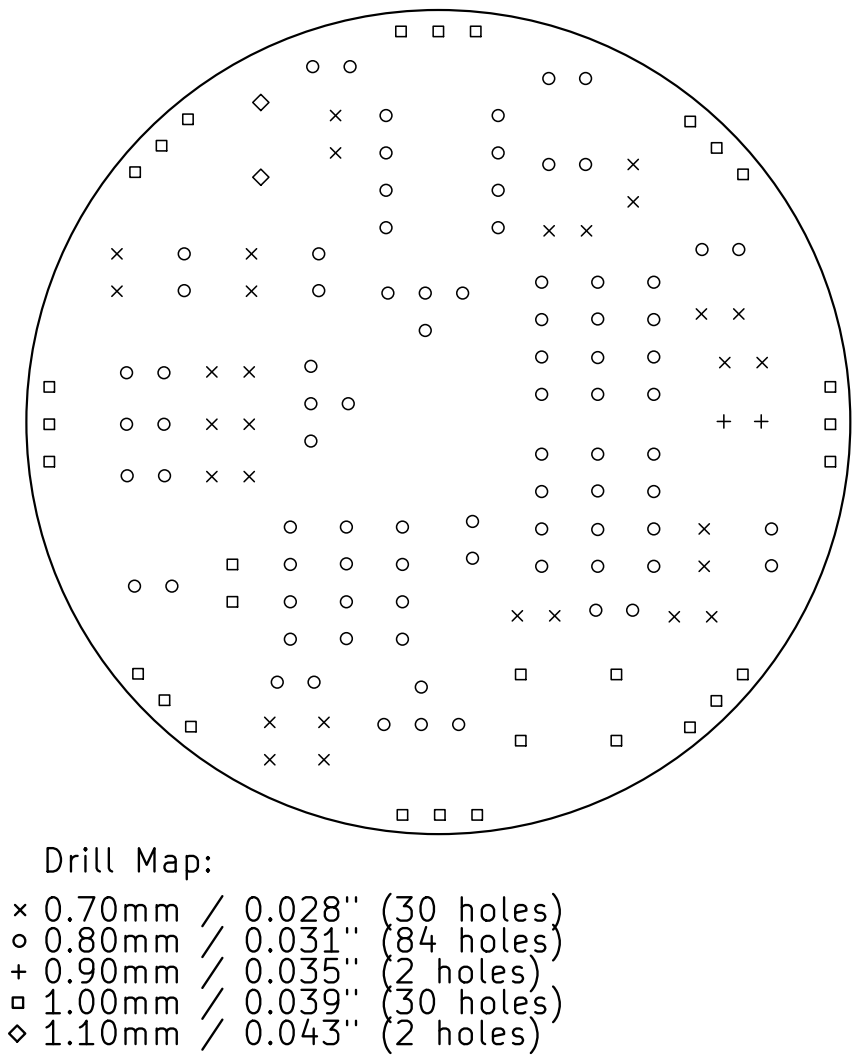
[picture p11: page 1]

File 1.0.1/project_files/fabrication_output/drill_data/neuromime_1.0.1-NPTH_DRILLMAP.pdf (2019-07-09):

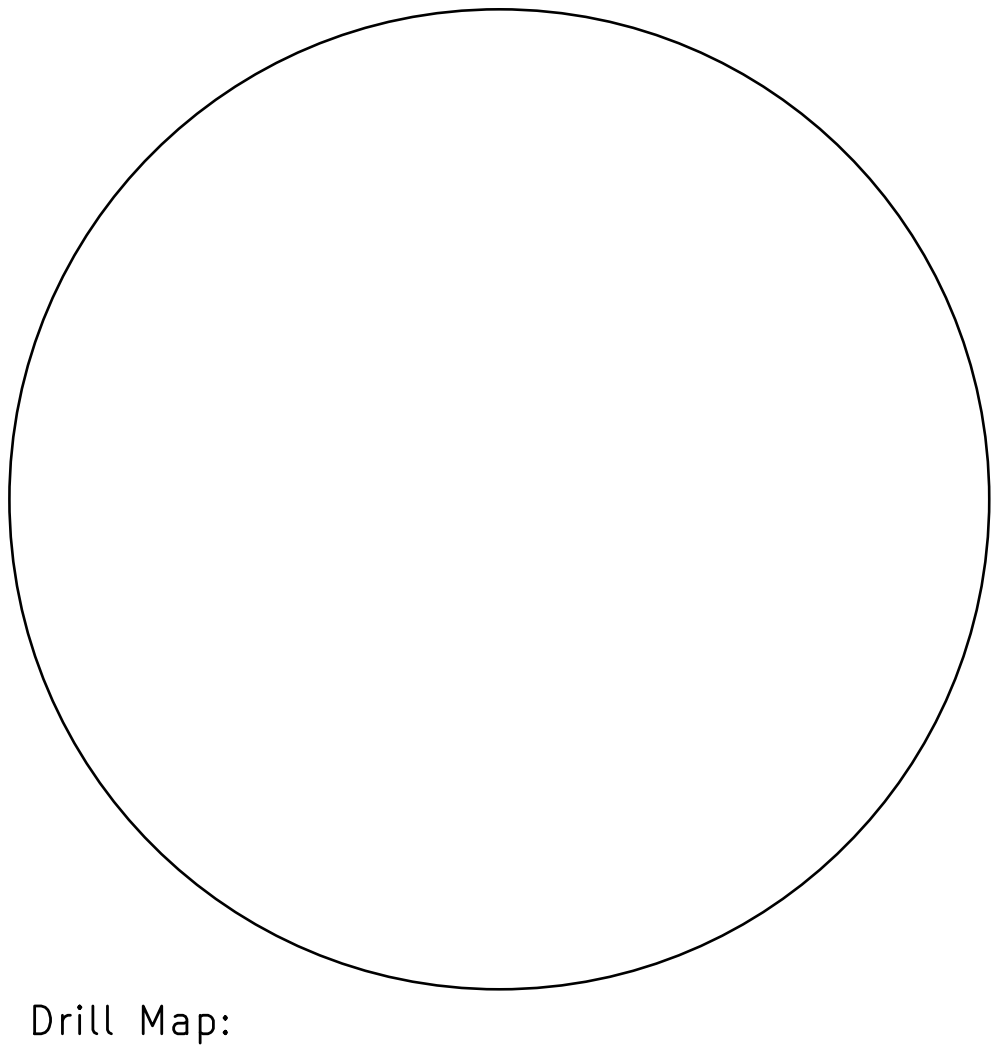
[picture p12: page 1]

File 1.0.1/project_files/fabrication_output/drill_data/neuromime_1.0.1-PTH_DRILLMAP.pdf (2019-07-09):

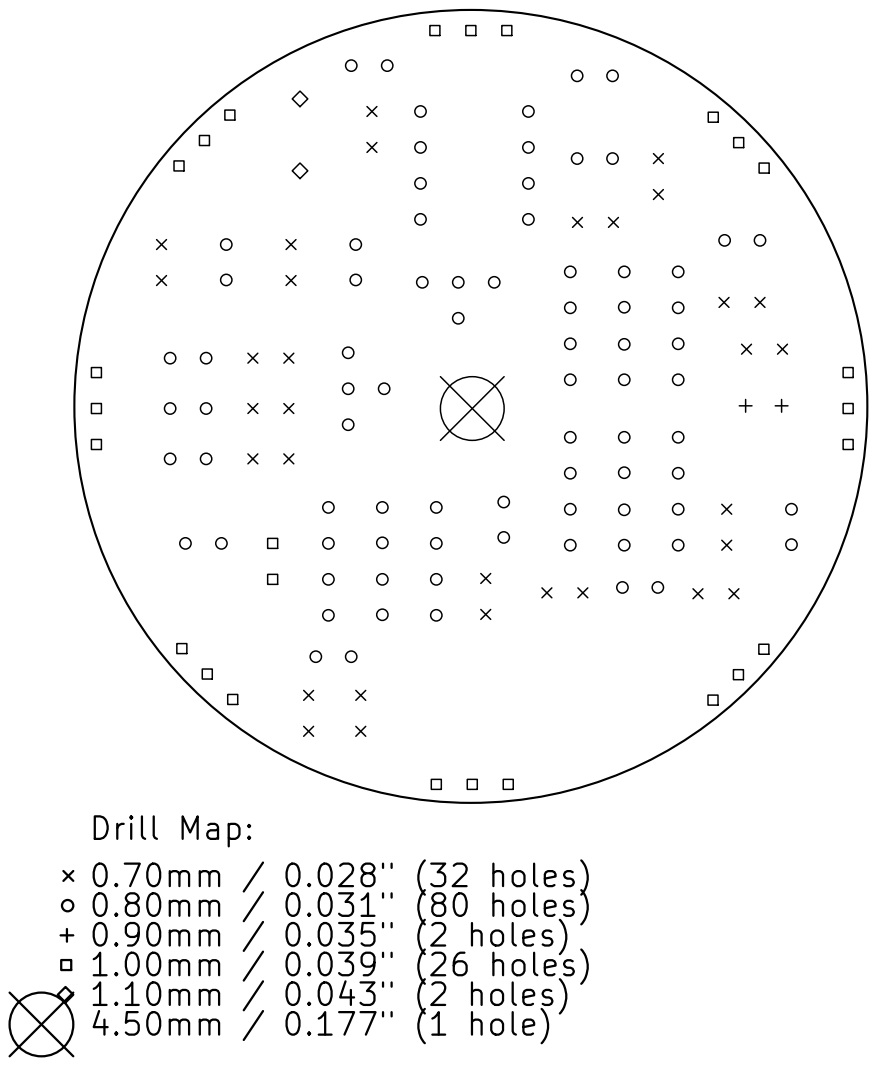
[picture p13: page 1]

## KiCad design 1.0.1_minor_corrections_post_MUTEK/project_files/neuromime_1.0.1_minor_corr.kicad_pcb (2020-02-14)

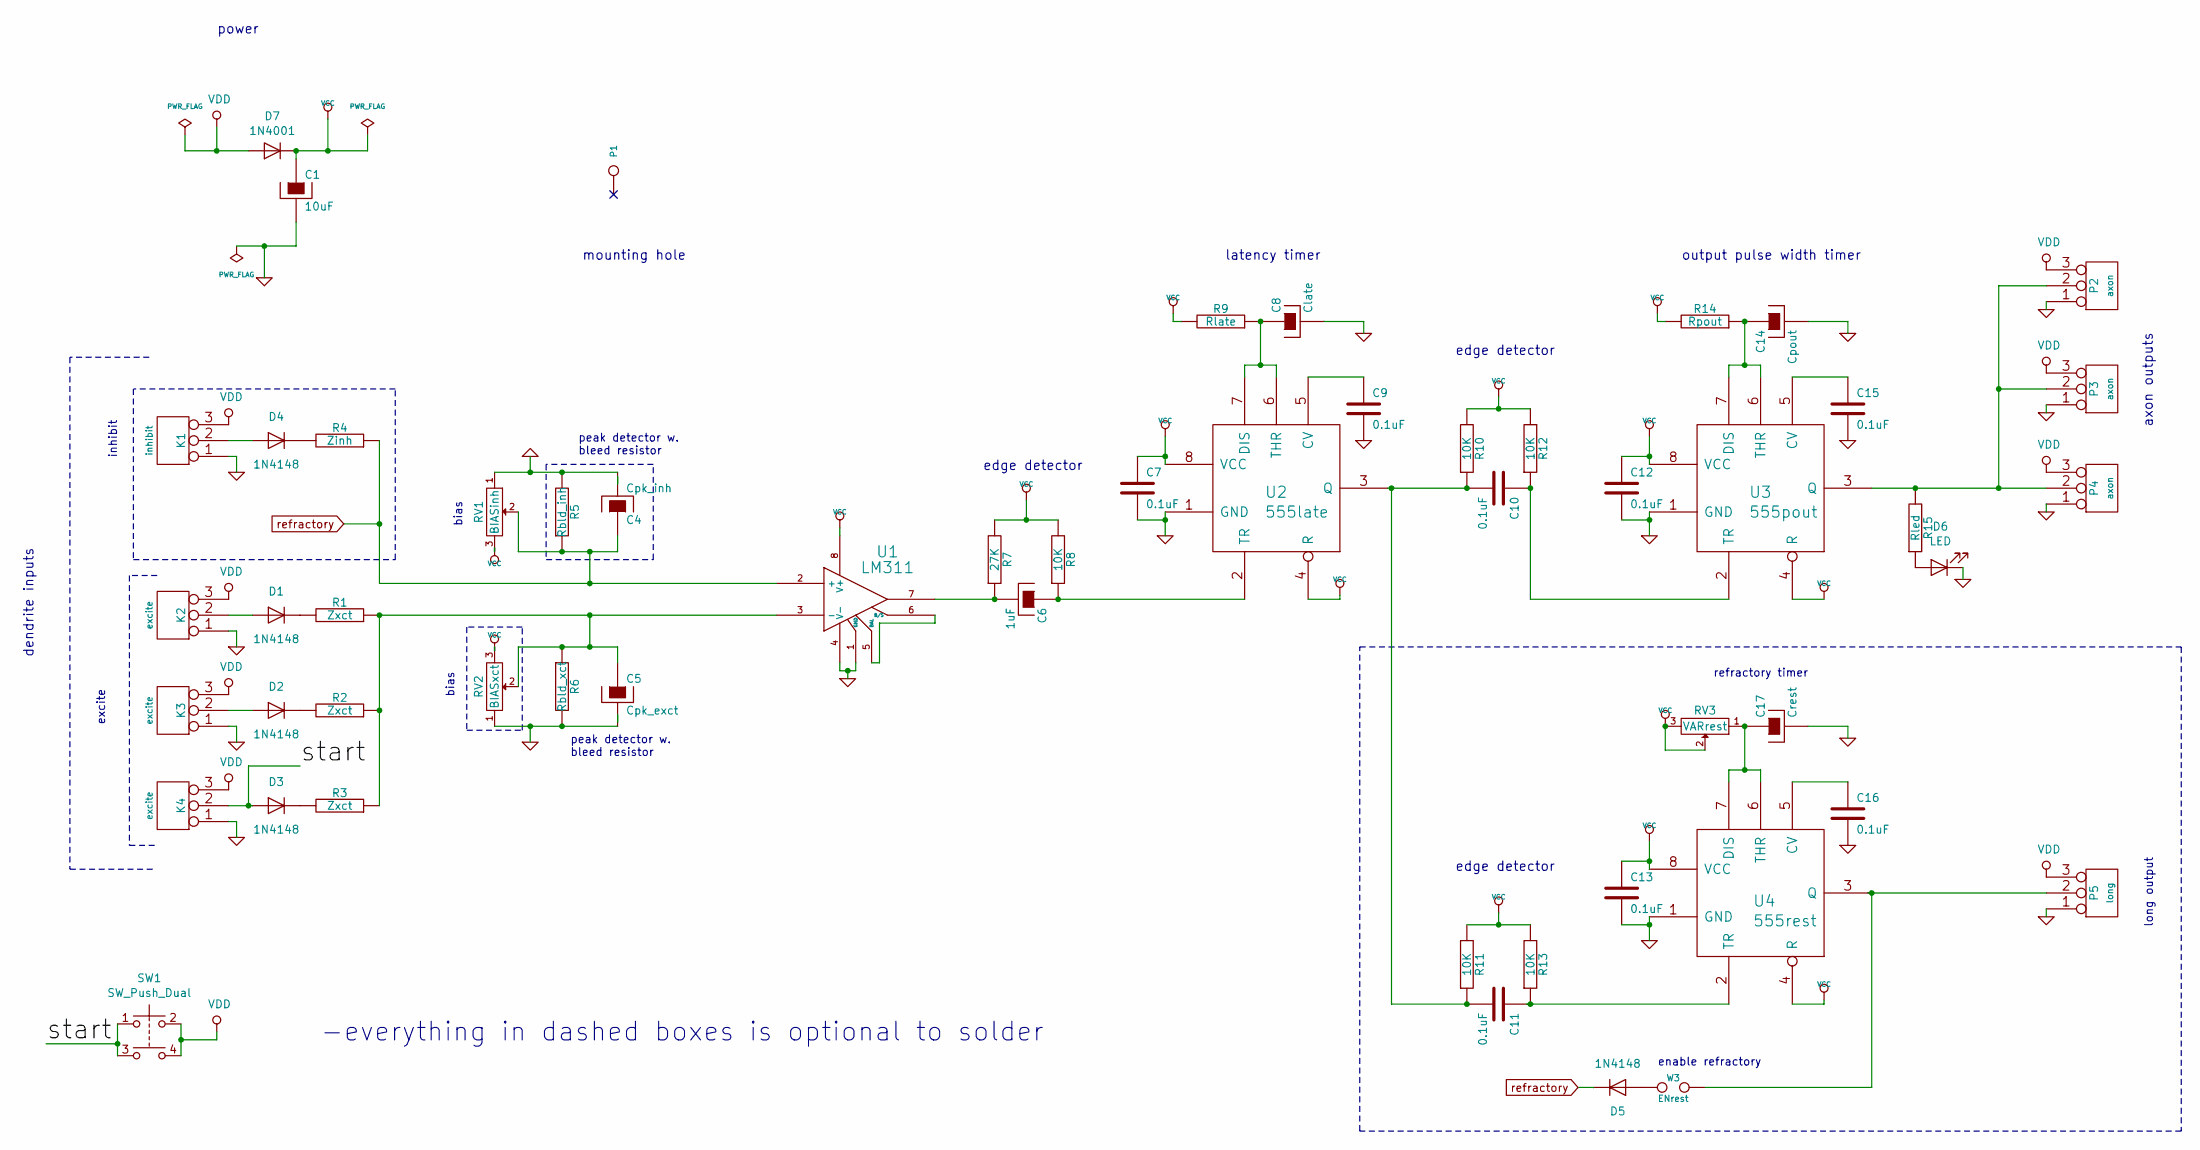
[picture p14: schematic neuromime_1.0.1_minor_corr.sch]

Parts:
C1: 10uF; CP_Radial_D5.0mm_P2.50mm_positive_symbol_inside
C4: Cpk_inh; CP_Radial_D5.0mm_P2.50mm_positive_symbol_inside
C5: Cpk_exct; CP_Radial_D5.0mm_P2.50mm_positive_symbol_inside
C6: 1uF; CP_Radial_D5.0mm_P2.50mm_positive_symbol_inside
C7, C9, C10, C11, C12, C13, C15, C16: 0.1uF; C_Disc_D3.0mm_W1.6mm_P2.50mm
C8: Clate; CP_Radial_D5.0mm_P2.50mm_positive_symbol_inside
C14: Cpout; CP_Radial_D5.0mm_P2.50mm_positive_symbol_inside_single_corr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
C17: Crest; CP_Radial_D5.0mm_P2.50mm_positive_symbol_inside
D1, D2, D3, D4, D5: 1N4148; D_DO-35_SOD27_P2.54mm_Vertical_KathodeUp
D6: LED; LED_D3.0mm
D7: 1N4001; D_DO-41_SOD81_P5.08mm_Vertical_KathodeUp
K1: inhibit; PinSocket_1x03_P2.54mm_Horizontal_elongated
K2, K3, K4: excite; PinSocket_1x03_P2.54mm_Horizontal_elongated
P1: mnt; MountingHole_4.5mm
P2, P3, P4: axon; PinHeader_1x03_P2.54mm_Horizontal_elomgated_pads
P5: long; PinHeader_1x03_P2.54mm_Horizontal_elomgated_pads
R1, R2, R3: Zxct; R_Axial_DIN0207_L6.3mm_D2.5mm_P2.54mm_Vertical_pad_numbers_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
R4: Zinh; R_Axial_DIN0207_L6.3mm_D2.5mm_P2.54mm_Vertical_pad_numbers_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
R5: Rbld_inh; R_Axial_DIN0204_L3.6mm_D1.6mm_P2.54mm_Vertical
R6: Rbld_xct; R_Axial_DIN0204_L3.6mm_D1.6mm_P2.54mm_Vertical
R7: 27K; R_Axial_DIN0204_L3.6mm_D1.6mm_P2.54mm_Vertical
R8, R10, R11, R12, R13: 10K; R_Axial_DIN0204_L3.6mm_D1.6mm_P2.54mm_Vertical
R9: Rlate; R_Axial_DIN0204_L3.6mm_D1.6mm_P2.54mm_Vertical
R14: Rpout; R_Axial_DIN0204_L3.6mm_D1.6mm_P2.54mm_Vertical
R15: Rled; R_Axial_DIN0204_L3.6mm_D1.6mm_P2.54mm_Vertical
RV1: BIASinh; Potentiometer_Bourns_3266W_Vertical_pin_variation
RV2: BIASxct; Potentiometer_Bourns_3266W_Vertical_pin_variation
RV3: VARrest; Potentiometer_Bourns_3266W_Vertical_pin_variation
SW1: SW_Push_Dual; SW_TH_Tactile_Omron_B3F-10xx
U1: LM311; DIP-8_W7.62mm_Socket
U2: 555late; DIP-8_W7.62mm_Socket
U3: 555pout; DIP-8_W7.62mm_Socket
U4: 555rest; DIP-8_W7.62mm_Socket
W3: ENrest; PinHeader_1x02_P2.54mm_Vertical

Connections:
/start: D3.2 (A), K4.2 (PM), SW1.1, SW1.3
GND: C1.2, C4.2, C5.2, C7.2, C8.2, C9.2, C12.2, C13.2, C14.2, C15.2, C16.2, C17.2, D6.1 (K), K1.1, K2.1, K3.1, K4.1, P2.1, P3.1, P4.1, P5.1, R5.2, R6.2, RV1.1, RV2.1, U1.1 (GND), U1.4 (V-), U2.1 (GND), U3.1 (GND), U4.1 (GND)
unnamed: C5.1, R1.1, R2.1, R3.1, R6.1, RV2.2, U1.3 (-)
unnamed: C6.1, R8.1, U2.2 (TR)
unnamed: C6.2, R7.1, U1.7
unnamed: C8.1, R9.1, U2.6 (THR), U2.7 (DIS)
unnamed: C9.1, U2.5 (CV)
unnamed: C10.1, R12.1, U3.2 (TR)
unnamed: C10.2, C11.2, R10.1, R11.1, U2.3 (Q)
unnamed: C11.1, R13.1, U4.2 (TR)
unnamed: C14.1, R14.1, U3.6 (THR), U3.7 (DIS)
unnamed: C15.1, U3.5 (CV)
unnamed: C16.1, U4.5 (CV)
unnamed: C17.1, RV3.1, U4.6 (THR), U4.7 (DIS)
unnamed: D1.1 (K), R1.2
unnamed: D1.2 (A), K2.2 (PM)
unnamed: D2.1 (K), R2.2
unnamed: D2.2 (A), K3.2 (PM)
unnamed: D3.1 (K), R3.2
unnamed: D4.1 (K), R4.2
unnamed: D4.2 (A), K1.2 (PM)
unnamed: D5.2 (A), W3.1
unnamed: D6.2 (A), R15.1
unnamed: P2.2 (PM), P3.2 (PM), P4.2 (PM), R15.2, U3.3 (Q)
unnamed: P5.2 (PM), U4.3 (Q), W3.2
unnamed: U1.5 (BAL), U1.6 (B/S)
VCC: C1.1, C7.1, C12.1, C13.1, D7.1 (K), R7.2, R8.2, R9.2, R10.2, R11.2, R12.2, R13.2, R14.2, RV1.3, RV2.3, RV3.2, RV3.3, U1.8 (V+), U2.4 (R), U2.8 (VCC), U3.4 (R), U3.8 (VCC), U4.4 (R), U4.8 (VCC)
VDD: D7.2 (A), K1.3, K2.3, K3.3, K4.3, P2.3, P3.3, P4.3, P5.3, SW1.2, SW1.4
refractory: C4.1, D5.1 (K), R4.1, R5.1, RV1.2, U1.2 (+)

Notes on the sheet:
mounting hole
dendrite inputs
axon outputs
power
edge detector
output pulse width timer
latency timer
inhibit
excite
bias
peak detector w. bleed resistor
enable refractory
refractory timer
long output
-everything in dashed boxes is optional to solder

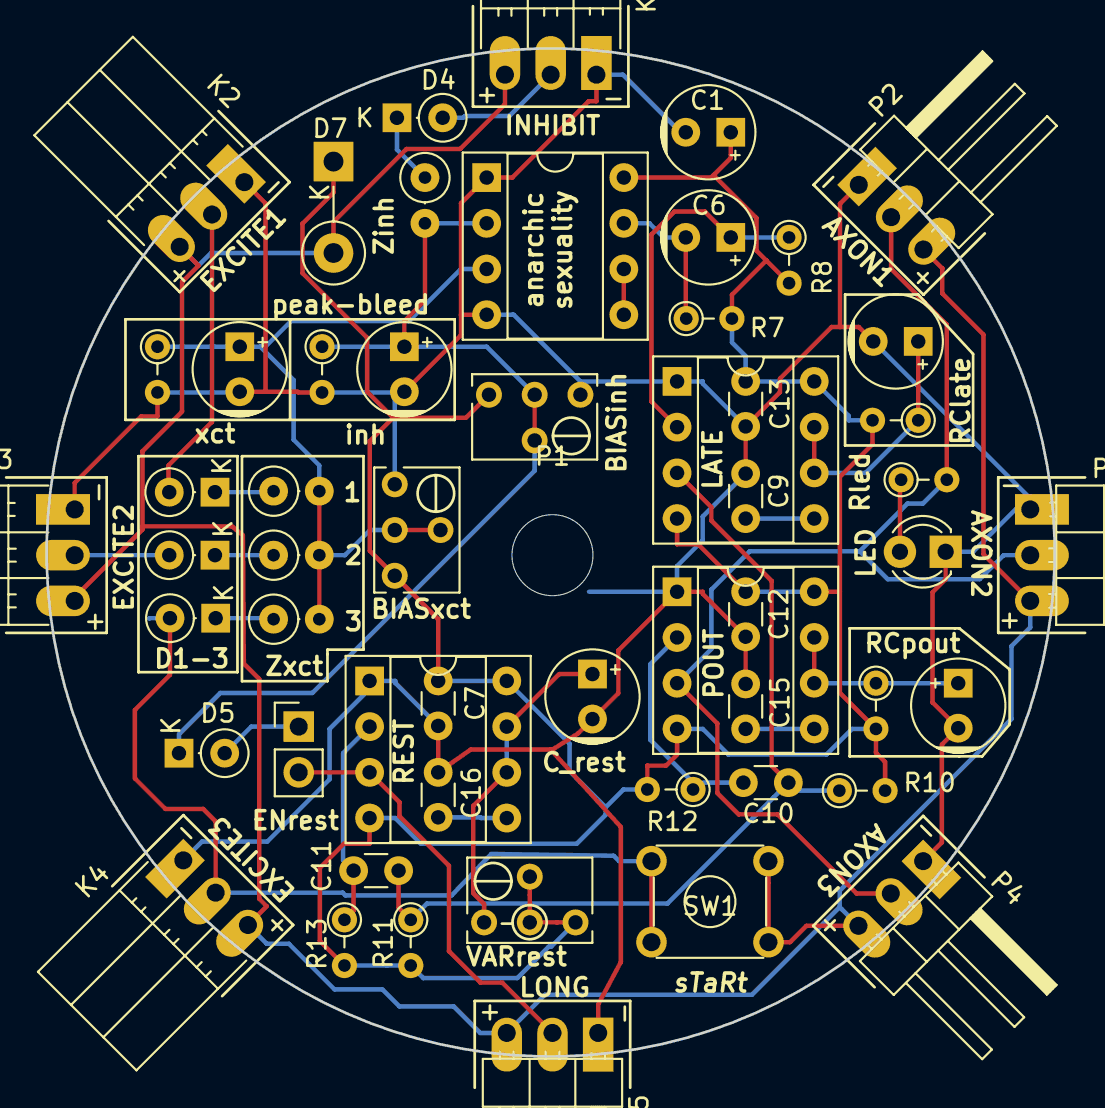
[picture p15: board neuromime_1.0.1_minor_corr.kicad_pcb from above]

Board: 2 copper layers, 56.0 x 56.0 mm, 55 parts (0 on the bottom side), 29 nets.

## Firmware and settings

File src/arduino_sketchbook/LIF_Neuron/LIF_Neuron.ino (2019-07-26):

/*
 * Simulation of leaky integrate-and-fire neuron
 * See: T. Trappenberg, "Fundamentals of Computational Neuroscience", Second Edition, Section 3.1.1 
 *
 * Note that inputs are "active low" in order to avoid external pulldown resistors.
 * Normal and inverted outputs are provided.
 */

//Parameters
const int numInput = 3;
float inverseTimeConstant = 0.1; 
float firingThreshold = 0.7; 
int spikeWidth = 3;

//IO pins
int spikeOutPin = 4;
int spikeInvertedOutPin = 5;
int membraneVoltageOutPin = 6;
int inputPins[] = {A0, A1, A2};


//Time dependent variables
float membraneVoltage = 0.0; 
float summedInputs;
int spikeTimer = 0;

void setup() { 
  Serial.begin(9600);  
  pinMode(spikeOutPin, OUTPUT);
  pinMode(spikeInvertedOutPin, OUTPUT);
  pinMode(membraneVoltageOutPin, OUTPUT);
  for (size_t i = 0; i < numInput; i++) pinMode(inputPins[i], INPUT_PULLUP);  
}

void loop() {
  
  //Sum inputs
  summedInputs = 0;
  for (size_t i = 0; i < numInput; i++) 
    summedInputs += digitalRead(inputPins[i]) == 0 ? 1 : 0; //inverted to avoid pulldowns
  
  //Spike (timer) logic
  if (spikeTimer > 0) 
    spikeTimer--;
  else if (membraneVoltage >= firingThreshold) {
      membraneVoltage = 0;
      spikeTimer = spikeWidth;
  }
  
  //Leaky integration
  membraneVoltage = (1 - inverseTimeConstant) * membraneVoltage + inverseTimeConstant * summedInputs;

  //Spike? 
  digitalWrite(spikeOutPin, spikeTimer > 0 ? HIGH : LOW);
  digitalWrite(spikeInvertedOutPin, spikeTimer > 0 ? LOW : HIGH);
  
  analogWrite(membraneVoltageOutPin, min(255, membraneVoltage / firingThreshold * 255));

  //Look at these with Tools -> Serial Plotter
  Serial.print(summedInputs);
  Serial.print(" ");
  Serial.print(membraneVoltage);
  Serial.print(" ");
  Serial.print(spikeTimer > 0 ? 2 : 0);
  Serial.print(" ");
  Serial.println(firingThreshold);

  delay(20);
}

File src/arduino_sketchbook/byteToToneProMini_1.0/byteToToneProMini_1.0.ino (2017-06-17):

#define BITS_IN_BYTE 8
//#define TONE_DURATION 77
#define FREQ_MIN 20
#define FREQ_MAX 2000

byte b;
byte bPrev;
const long interval = 5;
unsigned long previousMillis = 0;
int tonePin = 3;
int ledPin = 13;

//8 pins to sample 1 byte
int byte1Pins[]={10,11,12,13,A0,A1,A2,A3};

void setup() {                
  for (int i = 0; i < BITS_IN_BYTE; i++)
    pinMode(byte1Pins[i], INPUT);
  pinMode(ledPin, OUTPUT); 
  Serial.begin(9600);
}

void loop() {
 // unsigned long currentMillis = millis();
 // if (currentMillis - previousMillis >= interval) {
 //   previousMillis = currentMillis;
    
    //sample byte, store in b
    b = 0;
    for (int i = 0; i < BITS_IN_BYTE; i++)
      if(digitalRead(byte1Pins[i])) b |= 1 << i;
      else b &= ~(1 << i);

    //I recently found bitWrite() and bitRead() helper functions.
    //This code could be simplified / made  more user friendly.
    //For example, alternative sample byte code:
    //for (int i = 0; i < BITS_IN_BYTE; i++)
    //   bitWrite(b,i, digitalRead(byte1Pins[i]));
    
    //map byte (0-255) to freq range and play tone
    if (b>0 && b != bPrev){
      //printBits(b);
      //Serial.print(" Setting tone: ");
      Serial.println(map(b,0,255,FREQ_MIN,FREQ_MAX));
      tone(tonePin, map(b,0,255,FREQ_MIN,FREQ_MAX));//,TONE_DURATION);
      bPrev = b;
    }
    else
     noTone(tonePin);

    //toggle led
    //digitalWrite(ledPin, !digitalRead(ledPin));
  //}
}

void printBits(byte myByte){
  for(byte mask = 0x80; mask; mask >>= 1)
    if(mask  & myByte) Serial.print('1');
    else Serial.print('0');
  Serial.println(" ");
}

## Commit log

2015-09-01 new file: 1.0.0/BOM.txt modified: 1.0.0/INDEX.txt new file: 1.0.0/INDEX.txt~ renamed: 1.0.0/neuromime_1.0.0-cache.dcm -> 1.0.0/project_files/neuromime_1.0.0-cache.dcm renamed: 1.0.0/neuromime_1.0.0-c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
    [neuromime_1.0.0.brd, neuromime_1.0.0.sch]
2015-09-01 first BOM
2017-03-14 starting smd version of board for EB residency
    [neuromime_1.0.1.brd, neuromime_1.0.1.sch]
2017-06-17 all kinds of new stuff, whatever
    [neuromime_1.0.1.sch]
2018-11-05 changed name of version 1.0.1 folder
    [neuromime_1.0.1.brd, neuromime_1.0.1.sch]
2018-11-05 deleted 1.0.1 version folder, will attempt to properly branch
    [neuromime_1.0.1.brd, neuromime_1.0.1.sch]
2019-06-29 (re) added folder for 1.0.1 to master branch, contains whiteboard sketches for schematic in _notes_ folder
2019-06-29 rescuing accidentally deleted items in 1.0.1 folder
    [neuromime_1.0.0-2018-11-04-21-16-39.sch, neuromime_1.1.0.brd, neuromime_1.1.0.sch]
2019-06-29 added pdf version of schematic in folder 1.0.0
    [neuromime_1.0.0-2019-06-30-00-20-11.sch]
2019-07-06 work on 1.0.1, a simplified version w. optional refractory and inhibit complexes; pdf schematic in project folder
    [neuromime_1.0.1.sch]
2019-07-06 work on 1.0.1 board; still messy; not routed
    [neuromime_1.0.0-2018-11-04-21-16-39.sch, neuromime_1.0.1.brd, neuromime_1.0.1.kicad_pcb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]
2019-07-06 work on 1.0.1 board; autoroute test
    [neuromime_1.0.1.dsn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]
2019-07-07 work on 1.0.1; increase autoroute spacing to .5mm; labelling
    [neuromime_1.0.1 (copy).sch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]
2019-07-07 work on 1.0.1;housekeeping; paths; included footprints libs
    [neuromime_1.0.1 (copy).sch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]
2019-07-08 almost final version; added pcbfab renaming and zipping script to utils; libray management
2019-07-09 added LIF Neuron Arduino code
2019-07-09 added reverse power protection diode; cleaned up labels on board; production ready... just needs one last little looksee from Stephen :)
    [neuromime_1.0.0-2019-07-08-18-24-22.sch, neuromime_1.0.1.dsn, neuromime_1.0.1.kicad_pcb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]
2019-07-17 BOM in project folder; as csv (possibly stale) and libreoffice spreadsheet (with links)
    [neuromime_1.0.1_BOM_no_inhibit_no_refractory.csv, neuromime_1.0.1_BOM_no_inhibit_no_refractory.ods]
2019-07-26 changed 1.0. 1 to 1.0.1
    [neuromime_1.0.1.dsn, neuromime_1.0.1.kicad_pcb, neuromime_1.0.1.sch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]
2019-07-26 tidying up...
    [neuromime_1.0.1.dsn, neuromime_1.0.1.kicad_pcb, neuromime_1.0.1.sch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]
2019-07-26 removed 1.0_space_.1
    [neuromime_1.0.1.dsn, neuromime_1.0.1.kicad_pcb, neuromime_1.0.1.sch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]
2019-07-26 update BOM with board label cross reference
    [neuromime_1.0.1_BOM_no_inhibit_no_refractory.ods]
2019-07-27 generate current pdf schematic
2019-08-02 update BOM
    [neuromime_1.0.1_BOM_no_inhibit_no_refractory.ods]
2020-02-14 update BOM in 1.0.1_minor_corr
    [neuromime_1.0.1_BOM_no_inhibit_no_refractory.ods, neuromime_1.0.1_BOM_no_inhibit_no_refractory.xls, neuromime_1.0.1_minor_corr.dsn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]
